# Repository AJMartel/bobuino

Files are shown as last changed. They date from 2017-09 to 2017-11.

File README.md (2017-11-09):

[:fr:](LISEZMOI.md) [:uk:](README.md)

# bobuino
atmega 1284 arduino compatible

design inspired of [Croos Road Fencing Center](http://www.crossroadsfencing.com/BobuinoRev17/) work

features:

- microSD card
- lcd display 82x48 pixels
- rotary encoder
- wifi esp8266

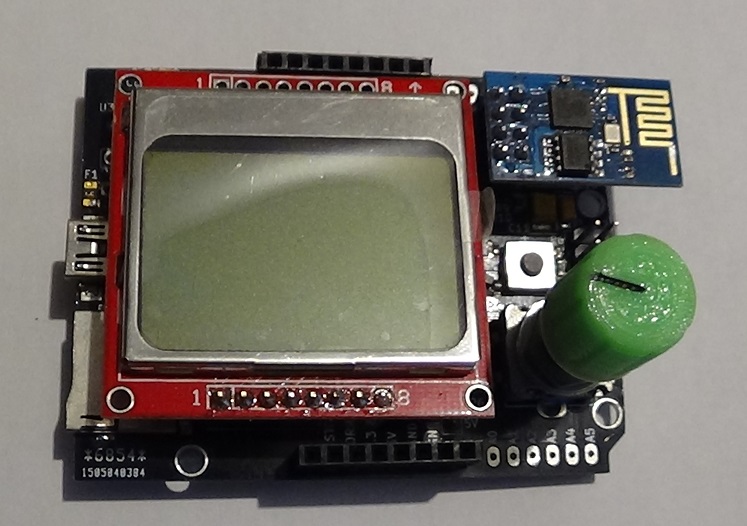
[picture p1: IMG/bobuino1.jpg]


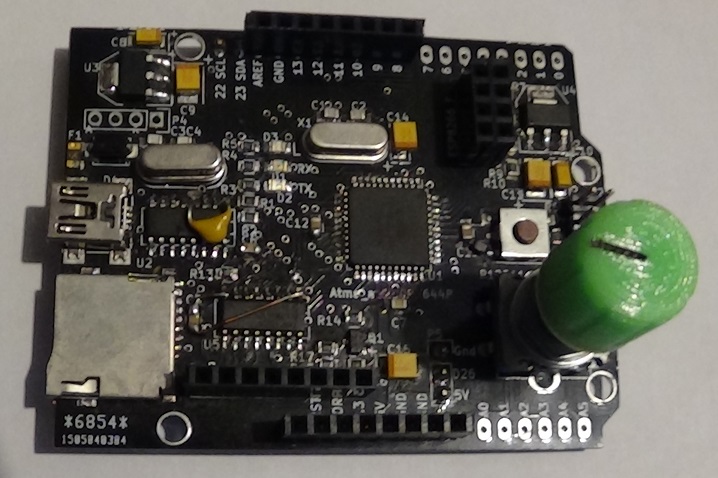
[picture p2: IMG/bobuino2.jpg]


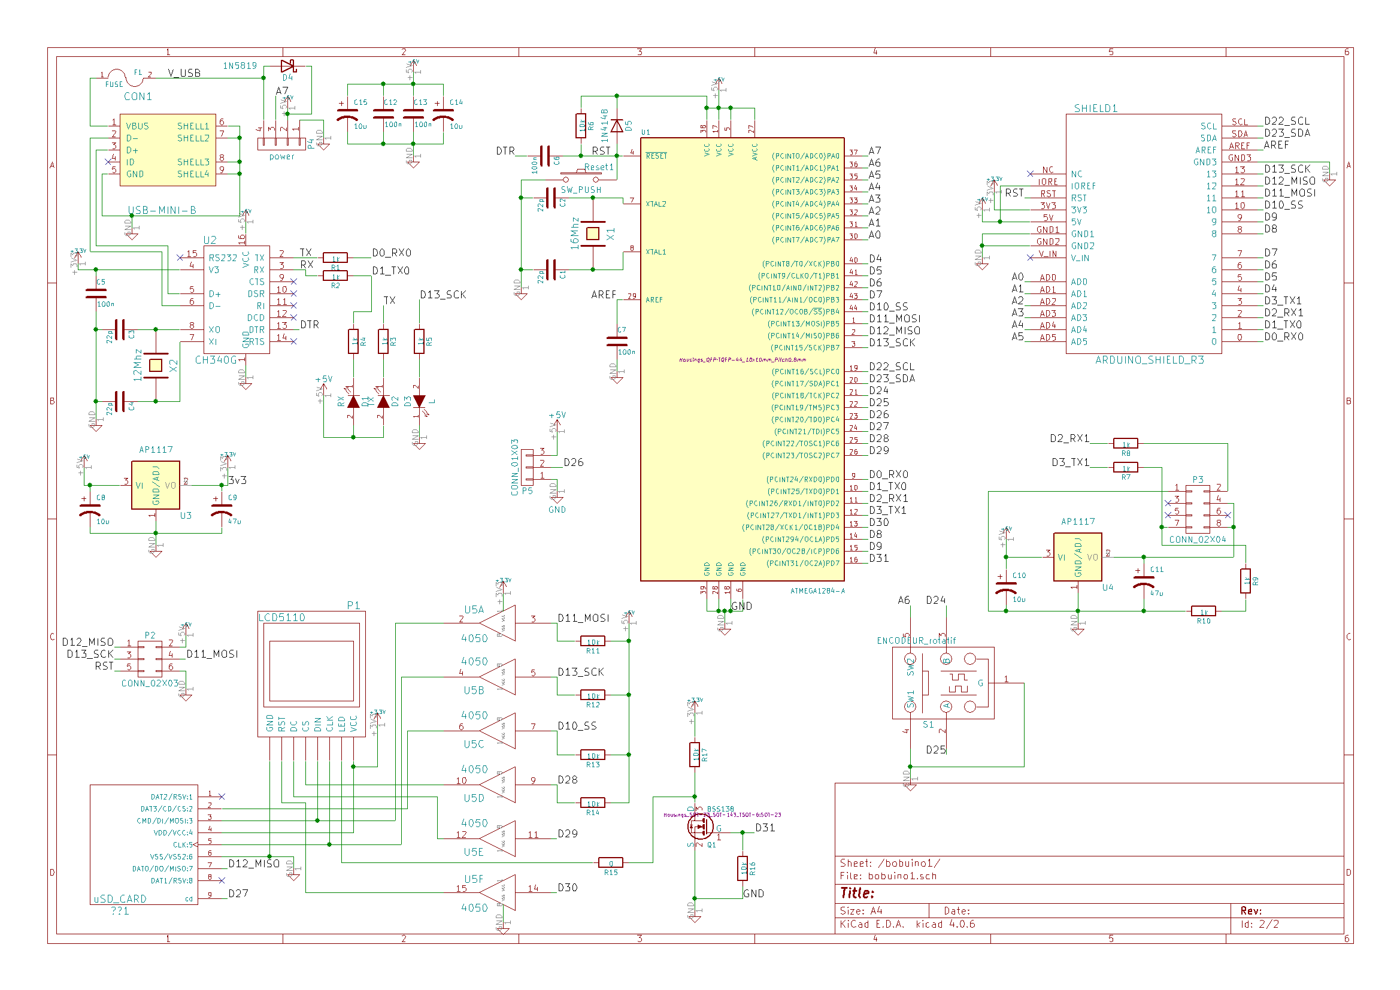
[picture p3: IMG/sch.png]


## Revisions

rev1 (/v1backup)
- U5 vcc and gnd are inverted !!!

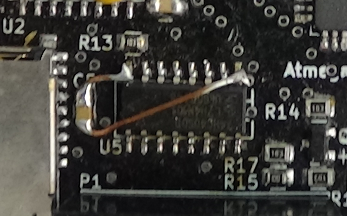
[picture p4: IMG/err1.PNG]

- D1 & D2 light when inactive
- 1n4148 is missing between vcc and rst

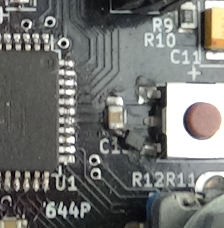
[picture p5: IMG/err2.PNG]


rev2 
- correct connection for U5, D1, D2 and D5

## How to install MightyCore
#### Boards Manager Installation
This installation method requires Arduino IDE version 1.6.4 or greater.
* Open the Arduino IDE.
* Open the **File > Preferences** menu item.
* Enter the following URL in **Additional Boards Manager URLs**: `https://mcudude.github.io/MightyCore/package_MCUdude_MightyCore_index.json`
  * Separate the URLs using a comma ( **,** ) if you have more than one URL
* Open the **Tools > Board > Boards Manager...** menu item.
* Wait for the platform indexes to finish downloading.
* Scroll down until you see the **MightyCore** entry and click on it.
* Click **Install**.
* After installation is complete close the **Boards Manager** window.

#### Manual Installation
On https://github.com/MCUdude/MightyCore , 
Click on the "Download ZIP" button. Extract the ZIP file, and move the extracted folder to the location "**~/Documents/Arduino/hardware**". Create the "hardware" folder if it doesn't exist.
Open Arduino IDE, and a new category in the boards menu called "MightyCore" will show up.

### Configuration
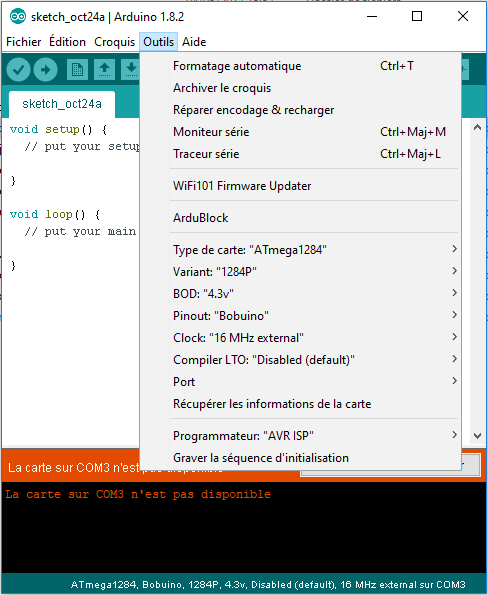
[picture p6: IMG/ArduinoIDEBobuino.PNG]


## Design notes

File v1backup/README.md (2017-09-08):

# bobuino
atmega 1284 arduino compatible

rev1 (/v1backup)
- U5 vcc and gnd are inverted !!!
- D1 & D2 light when inactive
- 1n4148 is missing between vcc and rst

rev2 
- correct connection for U5, D1, D2 and D5

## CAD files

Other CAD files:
v1backup/gerber/bobuino-F_Paste.dxf

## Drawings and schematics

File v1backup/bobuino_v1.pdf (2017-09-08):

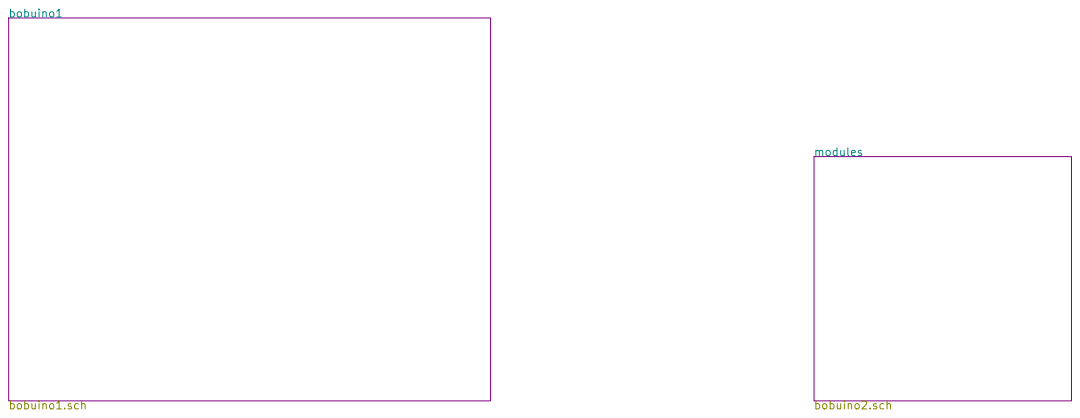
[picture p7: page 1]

Id: 1/3 Title: File: bobuino.sch Sheet: /

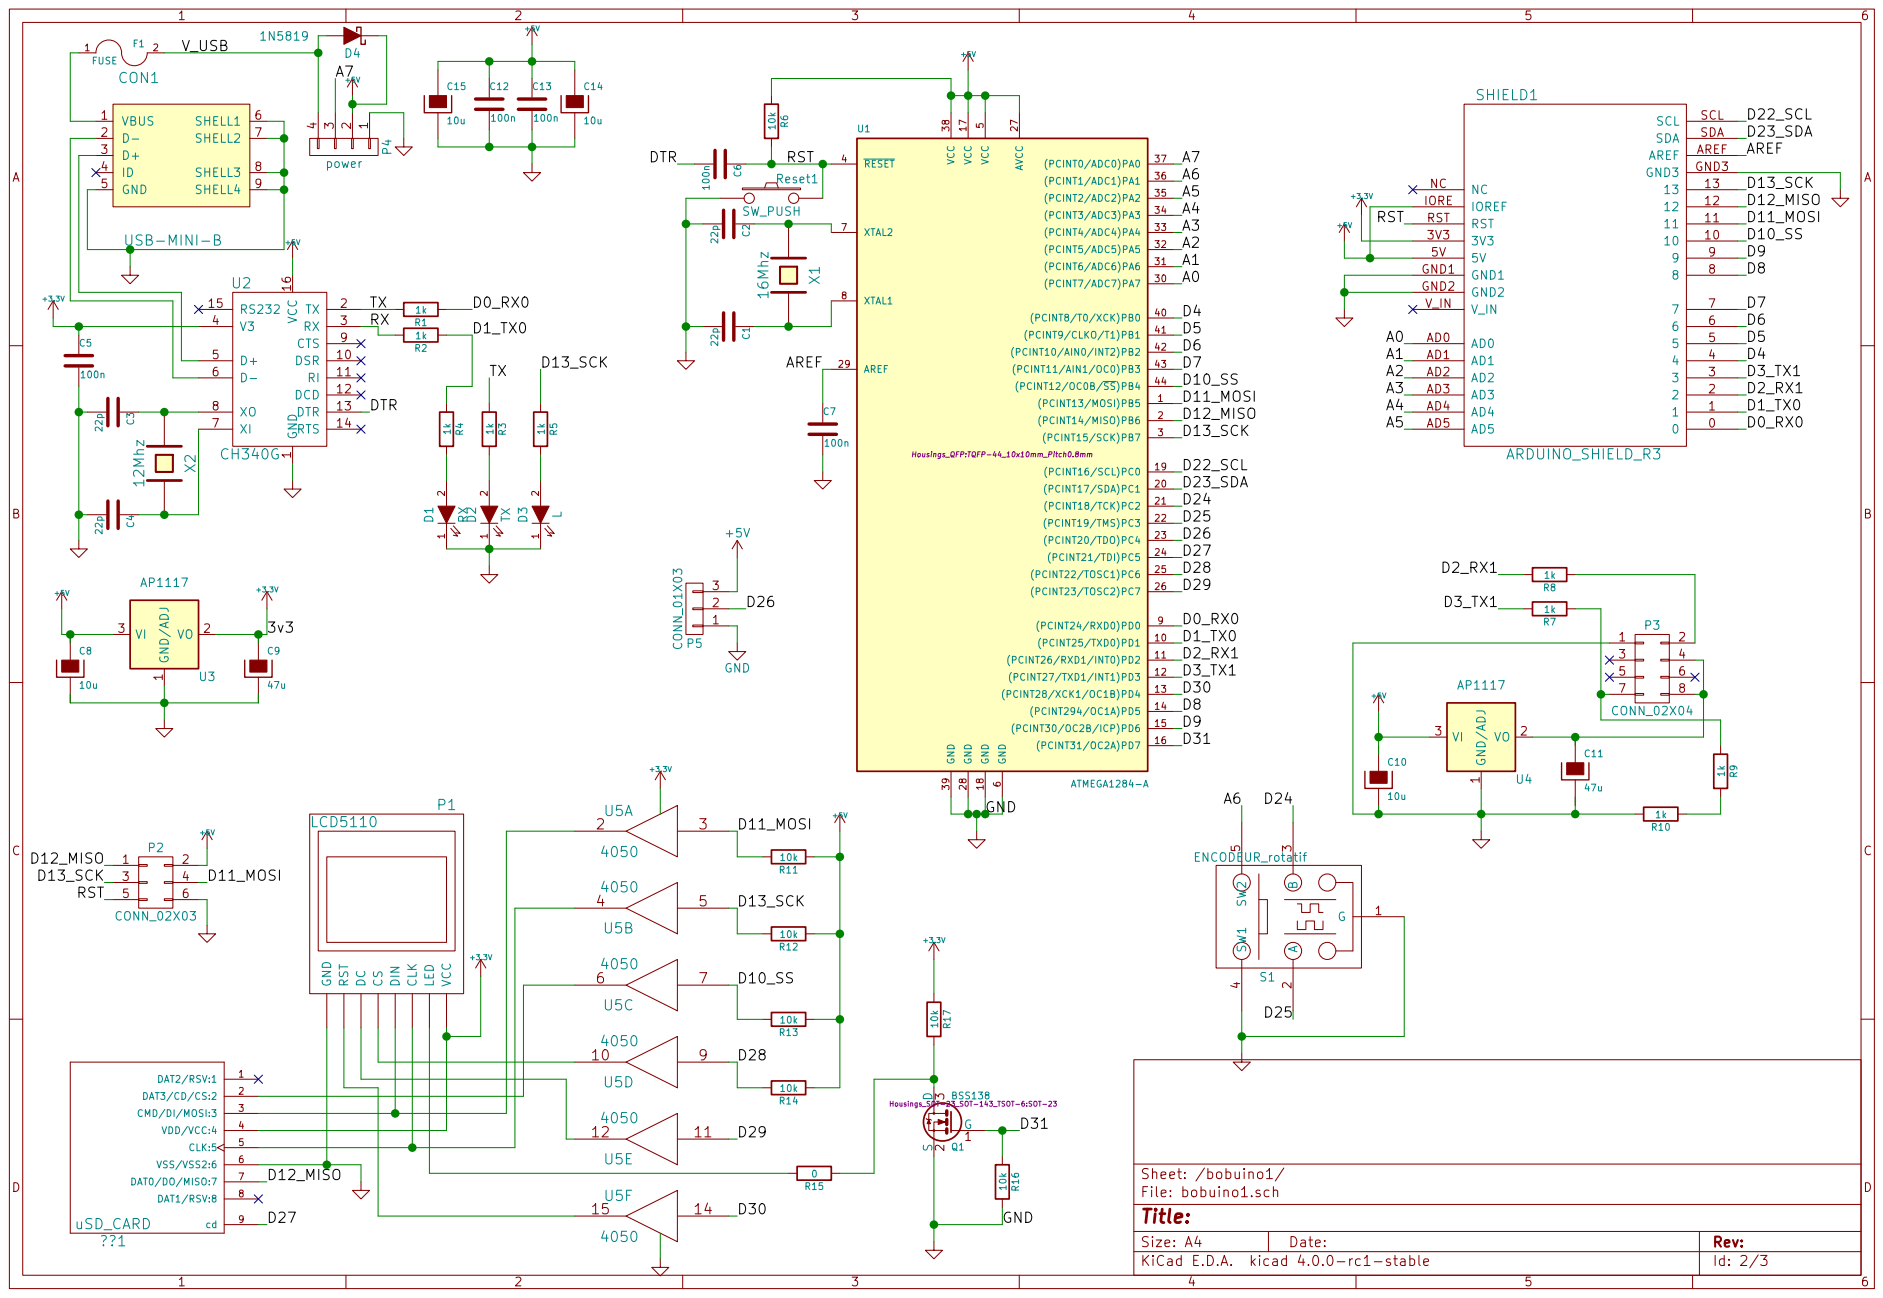
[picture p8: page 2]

1 TX 2 RX 3 V3 4 D+ 5 D- 6 XI 7 XO 8 CTS 9 DSR 10 RI 11 DCD 12 DTR 13 RTS 14 RS232 15 VCC U2 16

Id: 2/3 Title: File: bobuino1.sch Sheet: /bobuino1/

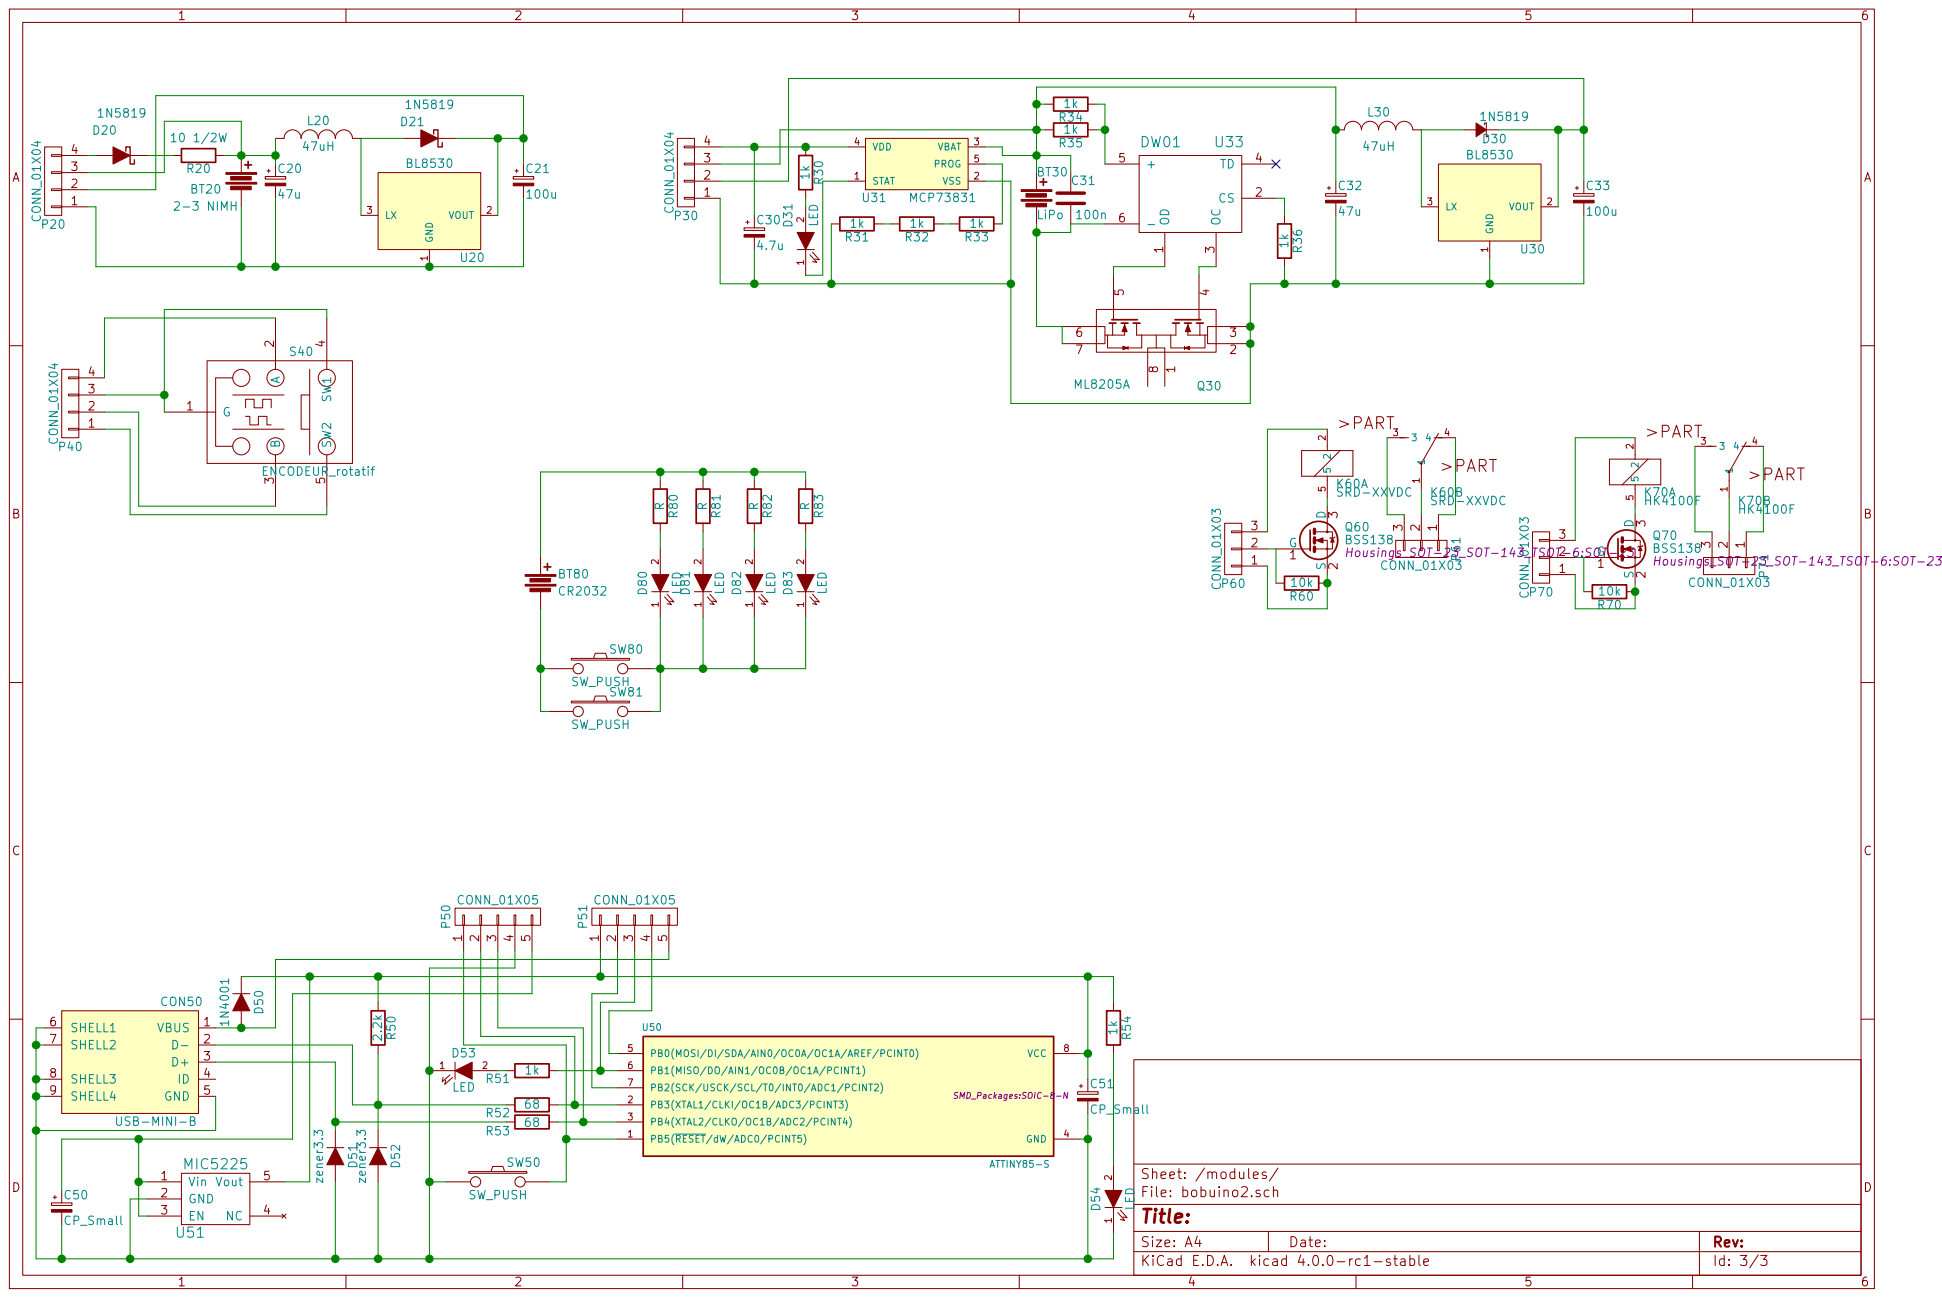
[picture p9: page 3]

1 2 D54 LEDC50 CP_Small Vin 1 GND 2 EN 3 NC 4 Vout 5 U51MIC5225 SW50 SW_PUSH

Id: 3/3 Title: File: bobuino2.sch Sheet: /modules/

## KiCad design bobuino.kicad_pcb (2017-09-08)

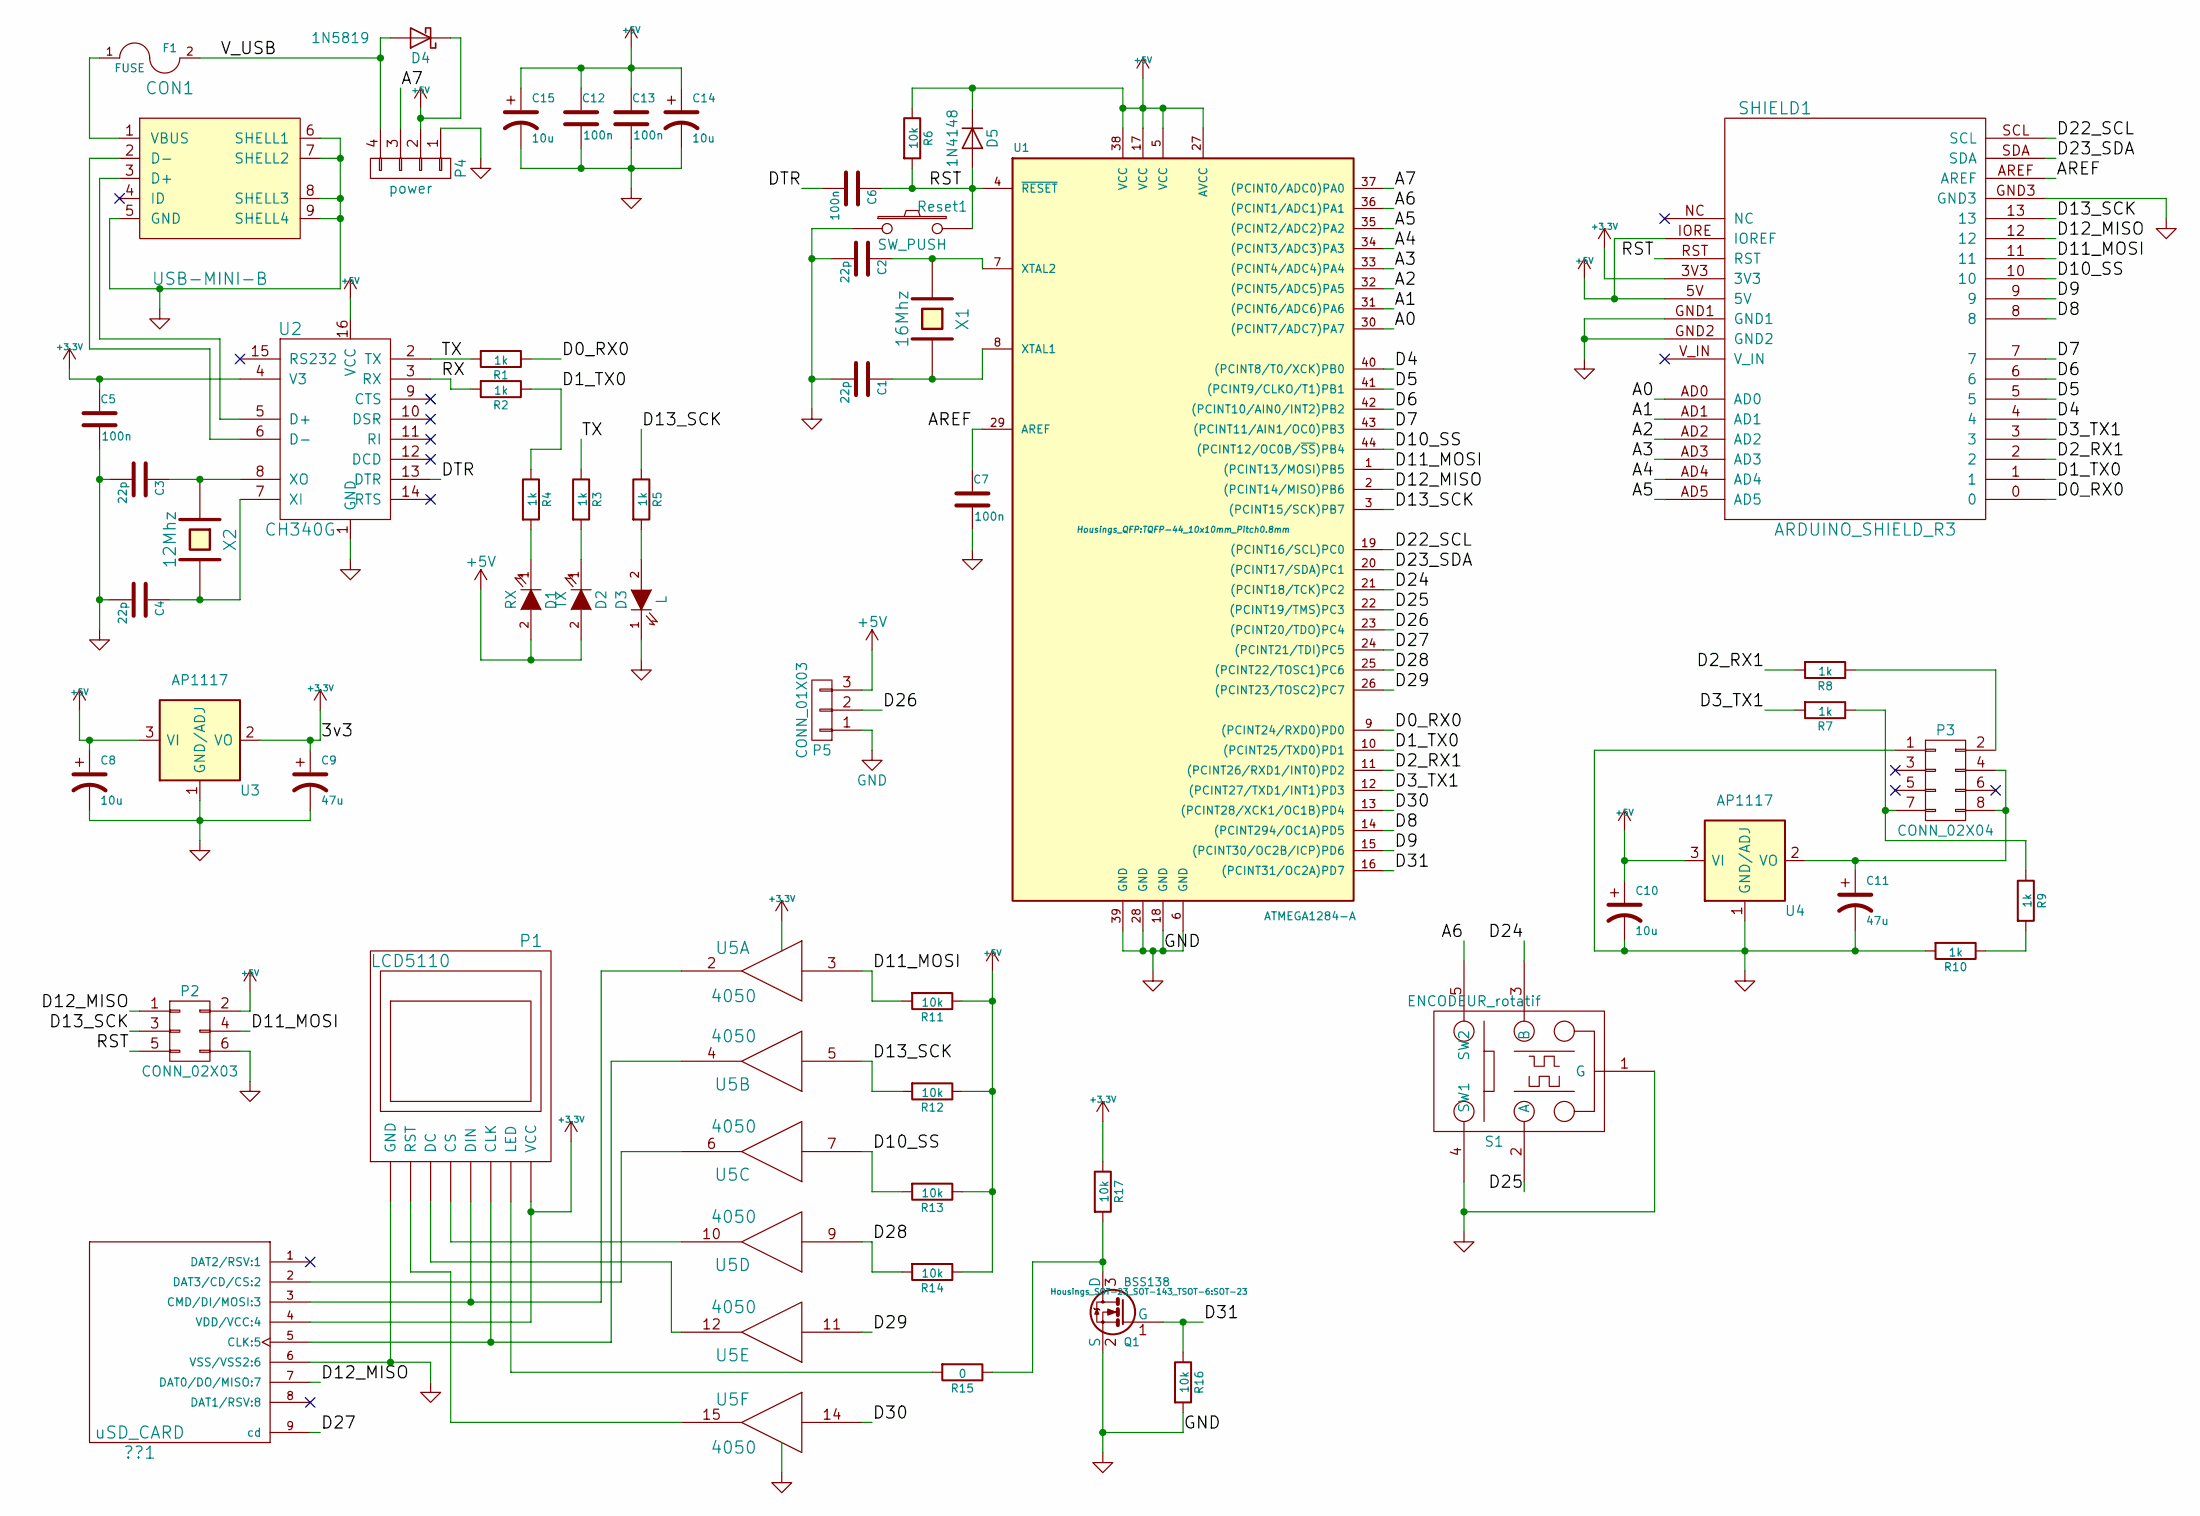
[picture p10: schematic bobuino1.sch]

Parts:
??1: uSD_CARD; MicroSD_alliexpress
C1, C2, C3, C4: 22p; C_0805
C5, C6, C7, C12, C13: 100n; C_0805
C8, C10, C14, C15: 10u; TantalC_SizeA_EIA-3216_Reflow
C9, C11: 47u; TantalC_SizeB_EIA-3528_Reflow
CON1: USB-MINI-B; USB_Mini-B
D1: RX; LED-0805
D2: TX; LED-0805
D3: L; LED-0805
D4: 1N5819; Diode-SMA_Standard
D5: 1N4148; SOD-123
F1: FUSE; Fuse_SMD1206_Reflow
P1: LCD5110; LCD5110_ali
P2: CONN_02X03; Pin_Header_Straight_2x03
P3: CONN_02X04; Pin_Header_Straight_2x04
P4: power; Socket_Strip_Straight_1x04
P5: CONN_01X03; Pin_Header_Straight_1x03
Q1: BSS138; SOT-23
R1, R2, R3, R4, R5, R7, R8, R9, R10: 1k; R_0805
R6, R11, R12, R13, R14, R16, R17: 10k; R_0805
R15: 0; R_0805
Reset1: SW_PUSH; SW_SPST_PTS645
S1: ENCODEUR_rotatif
SHIELD1: ARDUINO_SHIELD_R3
U1: ATMEGA1284-A; TQFP-44_10x10mm_Pitch0.8mm
U2: CH340G; SO-16-N
U3, U4: AP1117; SOT-223
U5: 4050; SO-16-N
X1: 16Mhz; Crystal_HC49-U_Vertical
X2: 12Mhz; Crystal_HC49-U_Vertical

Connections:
+3V3: ??1.4 (VDD/VCC:4), C5.1, C9.1, P1.VCC, R17.1, SHIELD1.3V3, U2.4 (V3), U3.2 (VO), U3.4 (VO), U5.1 (VCC)
+5V: C8.1, C10.1, C12.1, C13.1, C14.1, C15.1, D1.2 (A), D2.2 (A), D4.1 (K), D5.1 (K), P2.2, P4.2, P5.3, R6.1, R11.1, R12.1, R13.1, R14.1, SHIELD1.5V, SHIELD1.IORE (IOREF), U1.5 (VCC), U1.17 (VCC), U1.27 (AVCC), U1.38 (VCC), U2.16 (VCC), U3.3 (VI), U4.3 (VI)
/bobuino1/A0: SHIELD1.AD0, U1.30 ((PCINT7/ADC7)PA7)
/bobuino1/A1: SHIELD1.AD1, U1.31 ((PCINT6/ADC6)PA6)
/bobuino1/A2: SHIELD1.AD2, U1.32 ((PCINT5/ADC5)PA5)
/bobuino1/A3: SHIELD1.AD3, U1.33 ((PCINT4/ADC4)PA4)
/bobuino1/A4: SHIELD1.AD4, U1.34 ((PCINT3/ADC3)PA3)
/bobuino1/A5: SHIELD1.AD5, U1.35 ((PCINT2/ADC2)PA2)
/bobuino1/A6: S1.5 (SW2), U1.36 ((PCINT1/ADC1)PA1)
/bobuino1/A7: P4.3, U1.37 ((PCINT0/ADC0)PA0)
/bobuino1/AREF: C7.1, SHIELD1.AREF, U1.29 (AREF)
/bobuino1/D0_RX0: R1.1, SHIELD1.0, U1.9 ((PCINT24/RXD0)PD0)
/bobuino1/D1_TX0: R2.1, R4.1, SHIELD1.1, U1.10 ((PCINT25/TXD0)PD1)
/bobuino1/D2_RX1: R8.2, SHIELD1.2, U1.11 ((PCINT26/RXD1/INT0)PD2)
/bobuino1/D3_TX1: R7.2, SHIELD1.3, U1.12 ((PCINT27/TXD1/INT1)PD3)
/bobuino1/D4: SHIELD1.4, U1.40 ((PCINT8/T0/XCK)PB0)
/bobuino1/D5: SHIELD1.5, U1.41 ((PCINT9/CLKO/T1)PB1)
/bobuino1/D6: SHIELD1.6, U1.42 ((PCINT10/AIN0/INT2)PB2)
/bobuino1/D7: SHIELD1.7, U1.43 ((PCINT11/AIN1/OC0)PB3)
/bobuino1/D8: SHIELD1.8, U1.14 ((PCINT294/OC1A)PD5)
/bobuino1/D9: SHIELD1.9, U1.15 ((PCINT30/OC2B/ICP)PD6)
/bobuino1/D10_SS: R13.2, SHIELD1.10, U1.44 ((PCINT12/OC0B/~SS~)PB4), U5.7
/bobuino1/D11_MOSI: P2.4, R11.2, SHIELD1.11, U1.1 ((PCINT13/MOSI)PB5), U5.3
/bobuino1/D12_MISO: ??1.7 (DAT0/DO/MISO:7), P2.1, SHIELD1.12, U1.2 ((PCINT14/MISO)PB6)
/bobuino1/D13_SCK: P2.3, R5.1, R12.2, SHIELD1.13, U1.3 ((PCINT15/SCK)PB7), U5.5
/bobuino1/D22_SCL: SHIELD1.SCL, U1.19 ((PCINT16/SCL)PC0)
/bobuino1/D23_SDA: SHIELD1.SDA, U1.20 ((PCINT17/SDA)PC1)
/bobuino1/D24: S1.3 (B), U1.21 ((PCINT18/TCK)PC2)
/bobuino1/D25: S1.2 (A), U1.22 ((PCINT19/TMS)PC3)
/bobuino1/D26: P5.2, U1.23 ((PCINT20/TDO)PC4)
/bobuino1/D27: ??1.9 (cd), U1.24 ((PCINT21/TDI)PC5)
/bobuino1/D28: R14.2, U1.25 ((PCINT22/TOSC1)PC6), U5.9
/bobuino1/D29: U1.26 ((PCINT23/TOSC2)PC7), U5.11
/bobuino1/D30: U1.13 ((PCINT28/XCK1/OC1B)PD4), U5.14
/bobuino1/D31: Q1.1 (G), R16.1, U1.16 ((PCINT31/OC2A)PD7)
/bobuino1/DTR: C6.2, U2.13 (DTR)
/bobuino1/RST: C6.1, D5.2 (A), P2.5, R6.2, Reset1.2, SHIELD1.RST, U1.4 (~RESET)
/bobuino1/RX: R2.2, U2.3 (RX)
/bobuino1/TX: R1.2, R3.1, U2.2 (TX)
/bobuino1/V_USB: D4.2 (A), F1.2, P4.4
GND: ??1.6 (VSS/VSS2:6), C1.2, C2.2, C3.2, C4.2, C5.2, C7.2, C8.2, C9.2, C10.2, C11.2, C12.2, C13.2, C14.2, C15.2, CON1.5 (GND), CON1.6 (SHELL1), CON1.7 (SHELL2), CON1.8 (SHELL3), CON1.9 (SHELL4), D3.1 (K), P1.GND, P2.6, P3.1, P4.1, P5.1, Q1.2 (S), R10.2, R16.2, Reset1.1, S1.1 (G), S1.4 (SW1), SHIELD1.GND1, SHIELD1.GND2, SHIELD1.GND3, U1.6 (GND), U1.18 (GND), U1.28 (GND), U1.39 (GND), U2.1 (GND), U3.1 (GND/ADJ), U4.1 (GND/ADJ), U5.8 (VSS)
unnamed: ??1.2 (DAT3/CD/CS:2), U5.6
unnamed: ??1.3 (CMD/DI/MOSI:3), P1.DIN, U5.2
unnamed: ??1.5 (CLK:5), P1.CLK, U5.4
unnamed: C1.1, U1.8 (XTAL1), X1.2
unnamed: C2.1, U1.7 (XTAL2), X1.1
unnamed: C3.1, U2.8 (XO), X2.1
unnamed: C4.1, U2.7 (XI), X2.2
unnamed: C11.1, P3.4, P3.8, U4.2 (VO), U4.4 (VO)
unnamed: CON1.1 (VBUS), F1.1
unnamed: CON1.2 (D-), U2.6 (D-)
unnamed: CON1.3 (D+), U2.5 (D+)
unnamed: D1.1 (K), R4.2
unnamed: D2.1 (K), R3.2
unnamed: D3.2 (A), R5.2
unnamed: P1.CS, U5.10
unnamed: P1.DC, U5.12
unnamed: P1.LED, R15.2
unnamed: P1.RST, U5.15
unnamed: P3.2, R8.1
unnamed: P3.7, R7.1, R9.1
unnamed: Q1.3 (D), R15.1, R17.2
unnamed: R9.2, R10.1

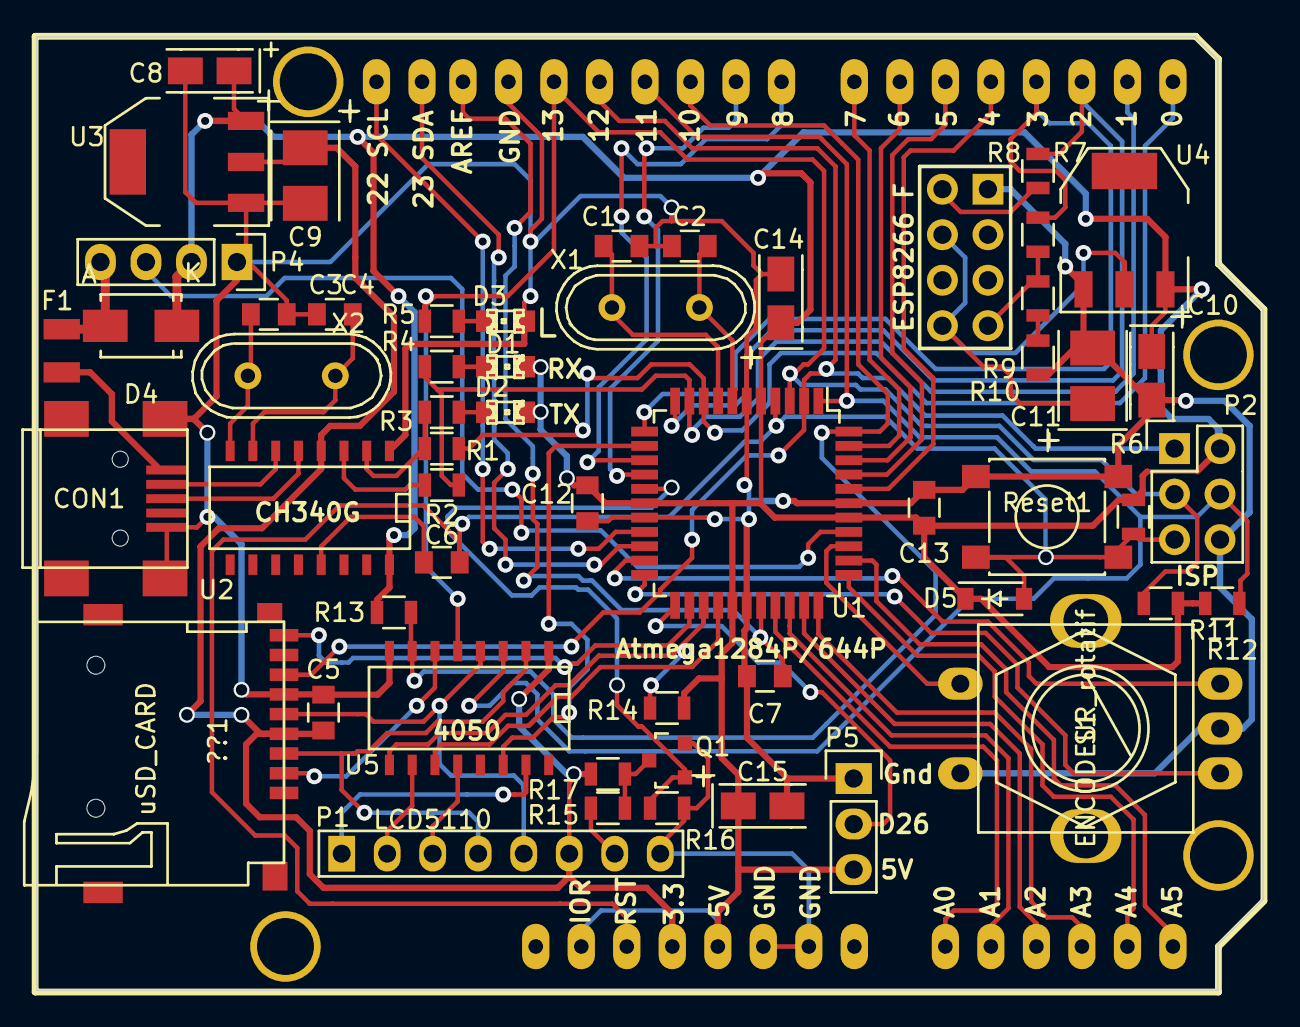
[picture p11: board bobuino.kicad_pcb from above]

Board: 2 copper layers, 68.5 x 53.2 mm, 56 parts (1 on the bottom side), 63 nets.
